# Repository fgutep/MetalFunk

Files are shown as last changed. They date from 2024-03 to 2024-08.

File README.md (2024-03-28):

# The metalFu(n)k 3D printer
Why call it that:
Used to be:
- A3D-One (When I was 16).
- MetalHunk (Because the full-metal frame is the best thing about it)
**Its now:**
- Metal Fuk. Because its a PITA. But being funky sounds kinder to it. 
------------

This 3D printer I started designing at the age of 16. Present day me is still suffering from the consequences of attempting to make such a thing without all the knowledge required. 
While it's been a very, very *edcuative* process, I'm now tryiong to make something useful out of it as it:
- Costed money to make (~400 USD then plus at least an aditional $100 while trying to make it work).
- Is a Pain in the 4$$.
- It would be nice to have a working 3D printer that I can proudly say "No one else in the world has this".
## Specs and Features:
- The sturdiest and most expensive frame you'll see in a while made fully of 2040 and 2020 T-Slot aluminum extrusion profiles.
- A BMG Bowden extruder.
- A custom (but full compromise) SLIM (and I mean **slim**) extruder I made for the Ender/CR Hotend.
- The novelty, antique and legendary **Ramps 1.4** which means it **runs on an Arduino Mega** <code style = "color : greenyellow">Will fix to support the Ender 3 -  4.2.7 Non-Silent Board OR the BIGTREETECH SKR Mini E3 V3.0).</code>.
- Marlin 2.0.1.
Double Z-Axis (Which is apparently a feature nowadays).
- <code style = "color : orangered"> Not a single V-Roller in sight besides being fully made in 2020 and 2040 T-Slot. Which is a problem. Will fix someday.</code>.

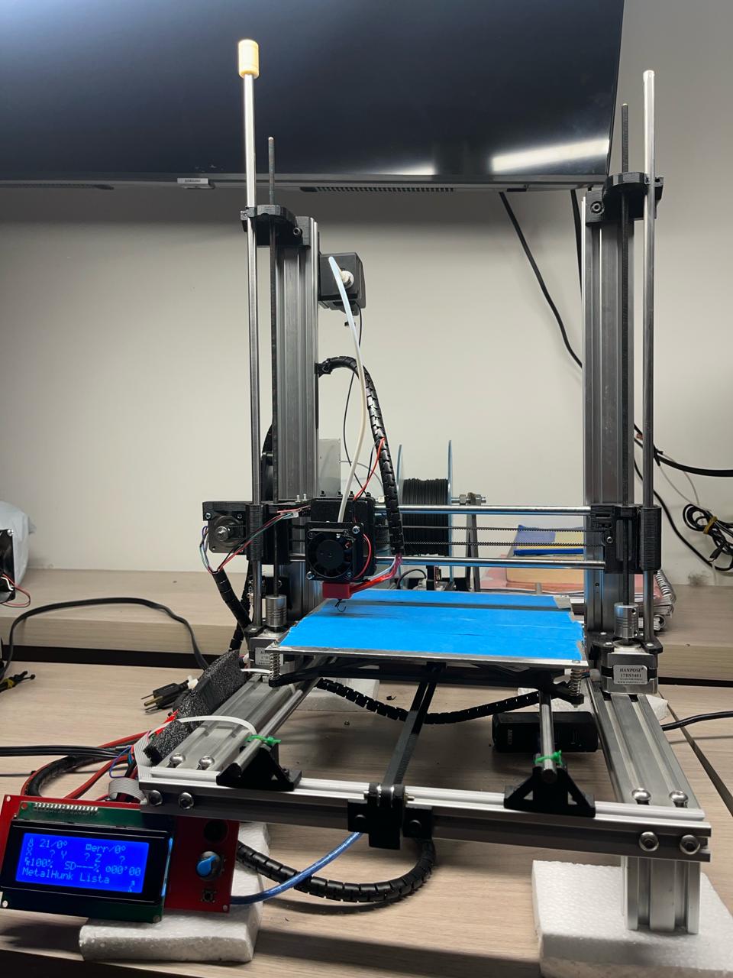
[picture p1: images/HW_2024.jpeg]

>> As of March 2024 it looks like this.

## Where am I with the development:
**Facts:**
- It has a decent and usable aluminum frame.
- It moves (It didnt use to).
- It does **not** caugh fire (it used to).
- It prints (Like *S*ugar *H*oney *I*ced *T*ea Tho).

### What I do not understand:
- The thing skips layers when printing anything above 40 minutes and starts shifting the object upfront making it unusable.
- Current of the motors. Only god and the guy who made them knows what current do they really use. While the *17HS3401* pancake Nema 17 motors i'm using have 1.2 Amps in their data sheet; they overheat a LOT when using that. Seem to run fine at 1/2 of the datasheet current and make a lot of noise anything below that.

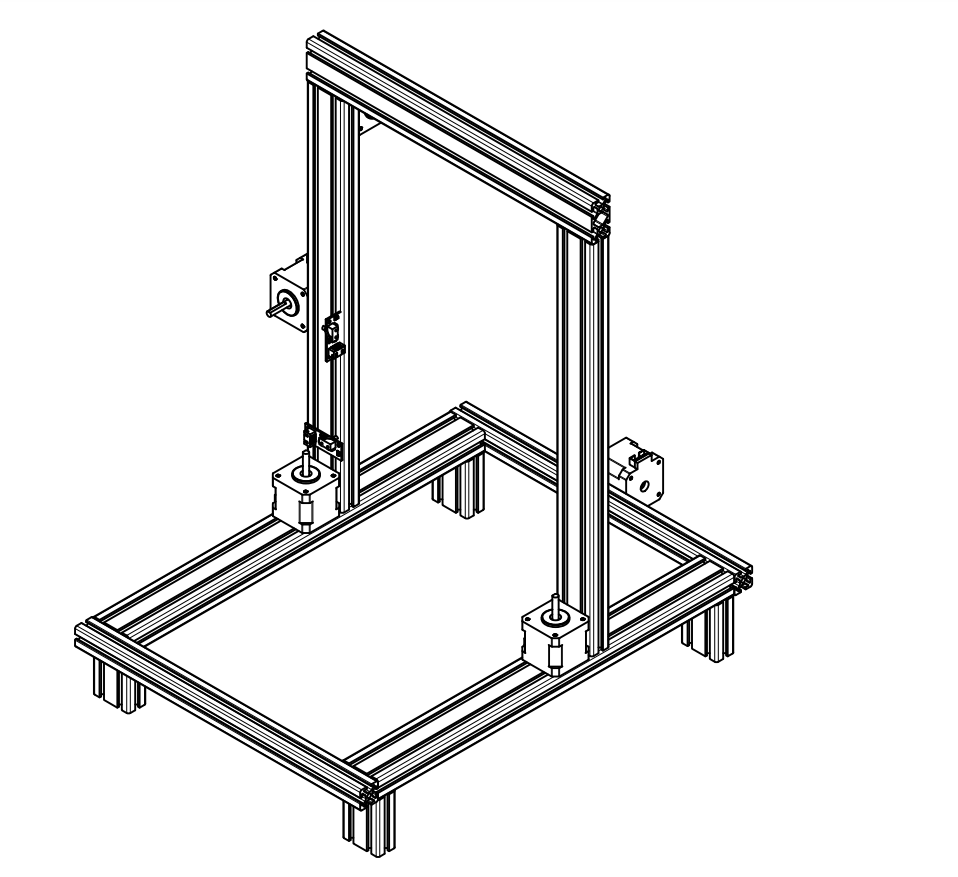
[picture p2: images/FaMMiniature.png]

>> The Uploaded CAD File. Note that only includes metal frame and motors/endStops as every plastic piece needs to be re-designed from scratch.

## Goals and To-Do:
- **1. Re-Design and re-print every.single.piece.of.plastic**. By this I mean every piece of 3D printed material as it's a frankenstein adaptation that I made between the [Prusa Rework](https://reprap.org/wiki/Prusa_i3_Rework_Introduction "Prusa Rework") that I was comftable since it was my first 3D printer and what I managed to make of those parts *i.e. in TinkerCAD* as an adaptation to the V-Slot profile frame.
- **2. Put a better board in it** like the aforementioned 4.2.7 Non-Silent Board OR the BIGTREETECH SKR Mini E3 V3.0. As I suspect 90% of my problems have to do with using *The Defunkt RAMPS*.
- **3. Make it print Reliably** Which I suspect with a new board in place, and with the new parts should be easier.
- **4. Extruder** Make it look pro, and add a colling fan, light and better cable management.
- **5. Asthetics** It looks like a *MetalHunk* it should look nice, or at the very least funny. It should have a personality to it.
- **6. Add V-Roller Based Kinematics** it is Unaceptable for it to use smooth rods and linear bearing in the date and time we are in.
- **7. The SkyisTheLimit** Input shapping, really high speeds, really quiet, wireless conectivity, the ability to print upsuide down or sideways. Whatever. But first we need to meet every previous objective.

When will the objectives be met?
When they are. I Hope that By Summer 2024 I am at least by objective **#4**. But I am not putting a hard deadline on it either as I am an EE and CS student and work with *a lot* of teams, sideprojects and sidequests on a daily basis appart from this one.  

*Note-to-self:* If By August 2024 objective #3 is not met, the project might be scrapped as the value to keep going might be usustainable. 

##### Last update of the readme:
27/03/2024

### Man Hours:
| When | Who | How Many |
| --- | --- | --- |
|  2019-2020 | Fgutep  | 50+ Hours  |
| Dec 2023- Jan 2024  | Fgutep  |  20+ Hours |
| March 2024 (Holy Week) | Fgutep  |  10+ Hours |
| |  Total ATM | ~80 Hours atleast  |

A free tip: Dont design, make and document a 3D printer as a 9th grade school project.

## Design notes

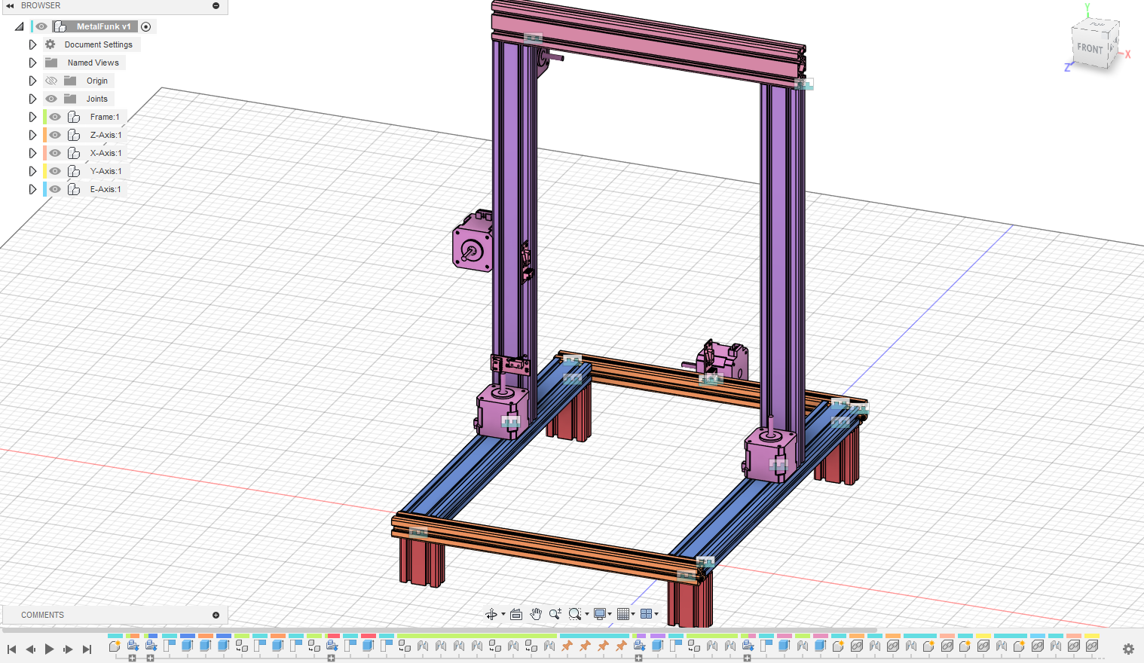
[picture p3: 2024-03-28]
images/F360_HW.png

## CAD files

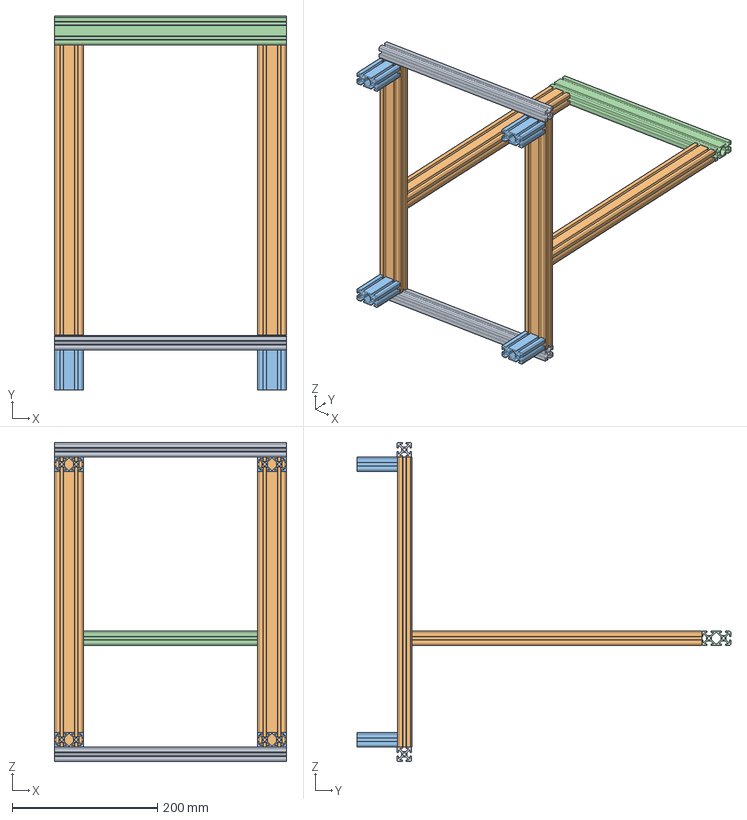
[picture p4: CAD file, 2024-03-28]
3DModels/Assembly/OnlyFrame.step
320.0 x 515.3 x 440.0 mm
2020- XA x 2
2040 - YA x 2
2040 - Z_Leg x 4
2040 - ZMain x 2
Frame Top

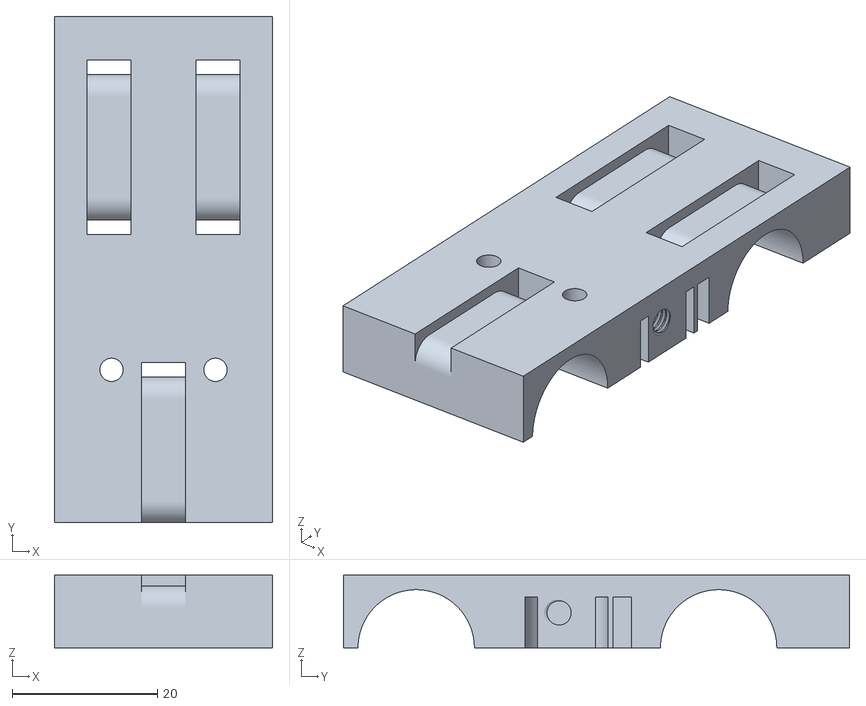
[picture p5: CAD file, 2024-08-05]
3DModels/X-Axis/Extruder/Extruder Back.stl
30.0 x 69.6 x 10.0

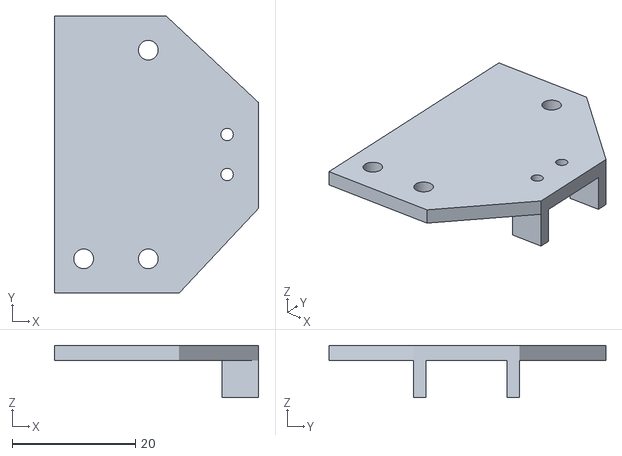
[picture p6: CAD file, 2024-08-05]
3DModels/X-Axis/X-Endstop-Adapter.stl
33.1 x 45.0 x 8.50

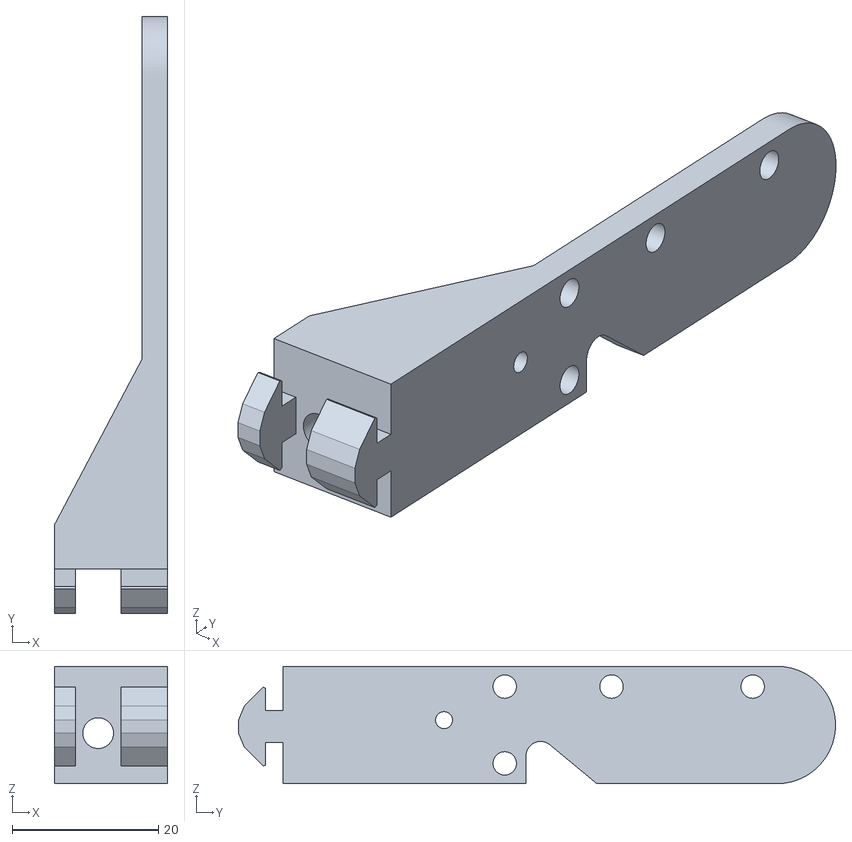
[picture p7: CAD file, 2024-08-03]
3DModels/Y-Axis/Y-EndStop.stl
15.5 x 81.6 x 16.0

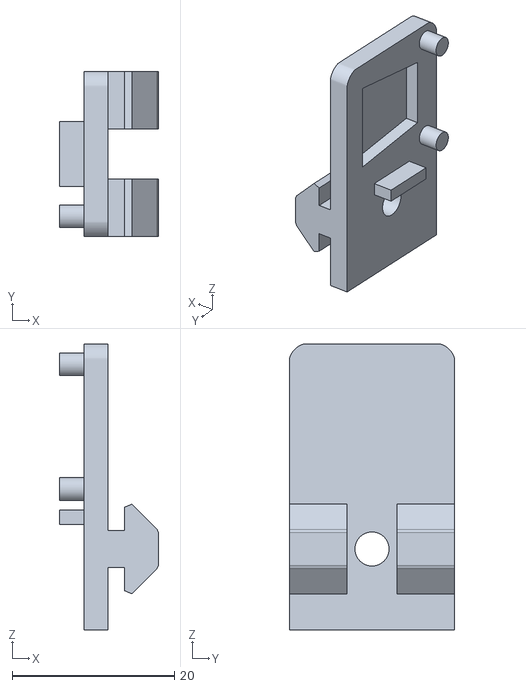
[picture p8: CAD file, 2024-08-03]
3DModels/Z-Axis/Z-Endstop-V1.stl
12.2 x 20.4 x 35.3

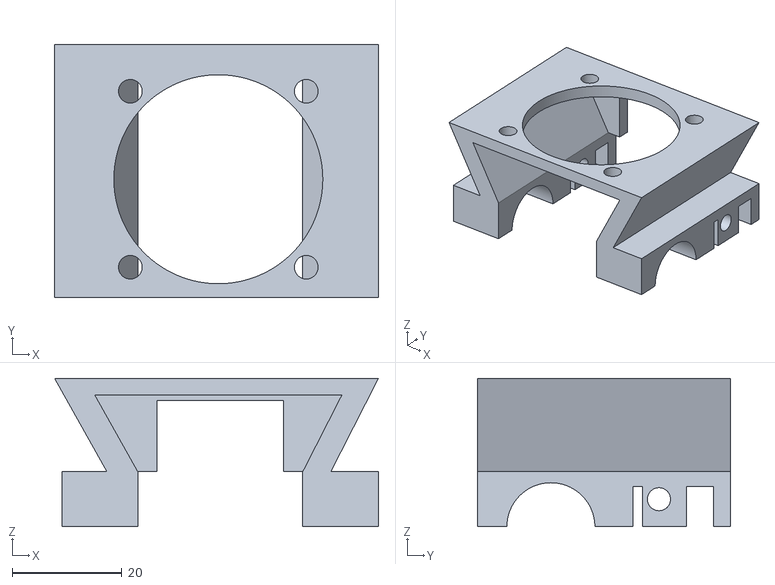
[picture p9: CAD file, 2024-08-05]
3DModels/X-Axis/Extruder/Extruder Shroud.stl
58.9 x 46.0 x 27.0

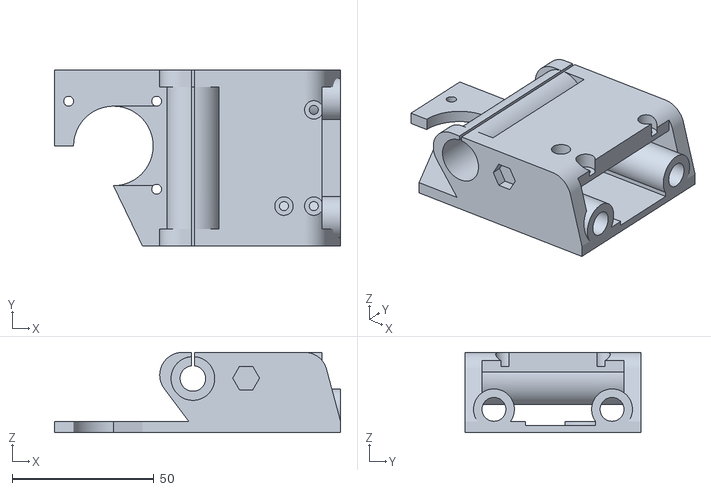
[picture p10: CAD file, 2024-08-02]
3DModels/X-Axis/X-Motor.stl
100.8 x 62.0 x 28.3

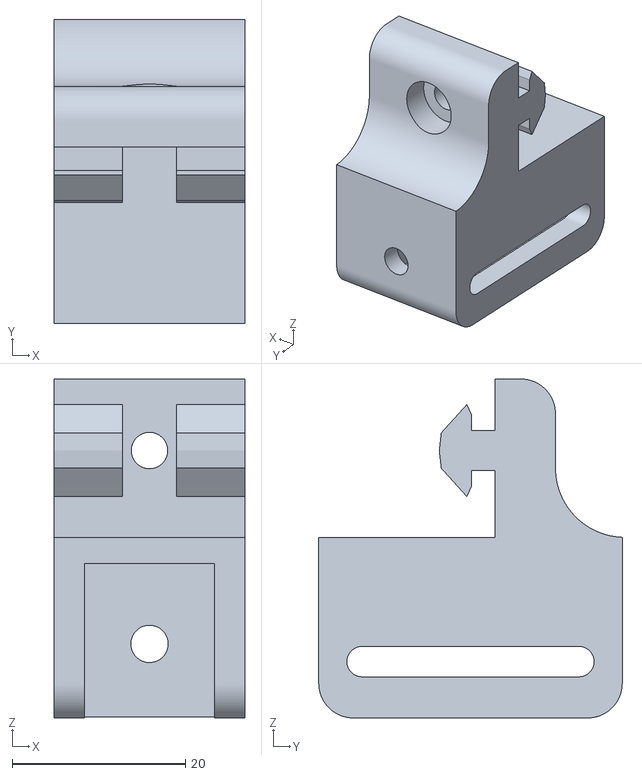
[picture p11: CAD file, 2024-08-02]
3DModels/Y-Axis/Y-Pulley-Tensioner.stl
22.0 x 35.0 x 39.1

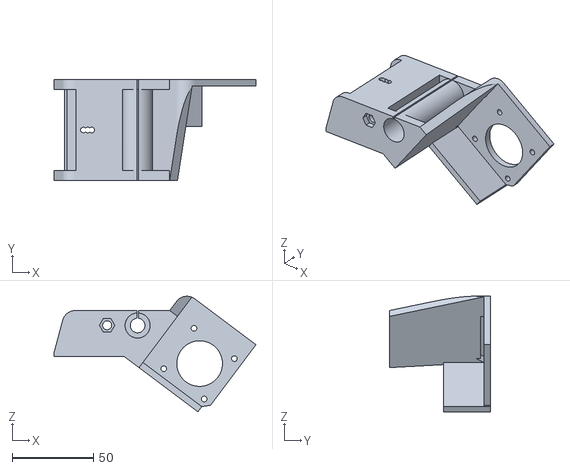
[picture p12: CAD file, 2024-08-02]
3DModels/X-Axis/X-Idler-and-BMG.stl
124.0 x 62.0 x 71.0

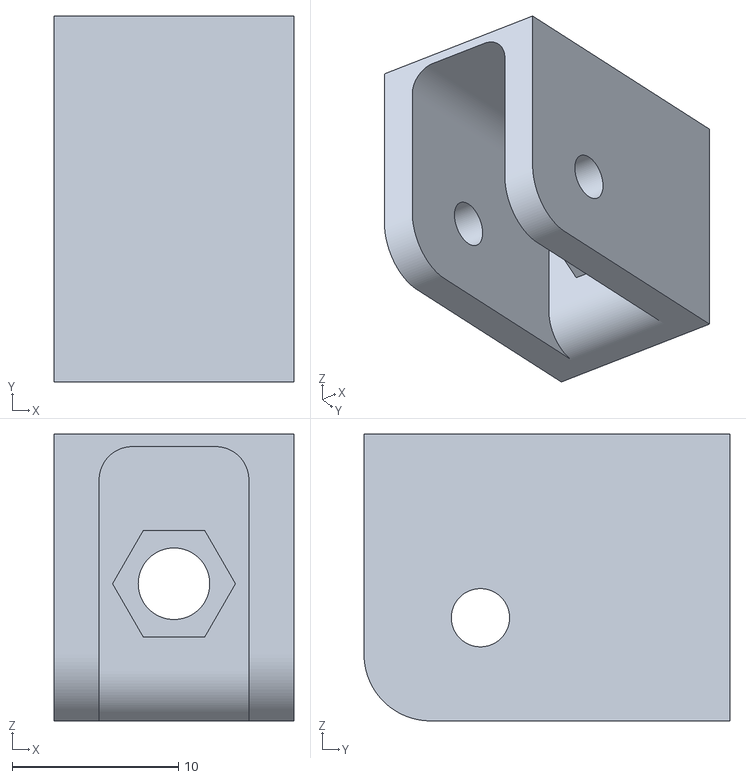
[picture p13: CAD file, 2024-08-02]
3DModels/Y-Axis/Y-Pulley Idler-Craddle.stl
14.4 x 22.0 x 17.2

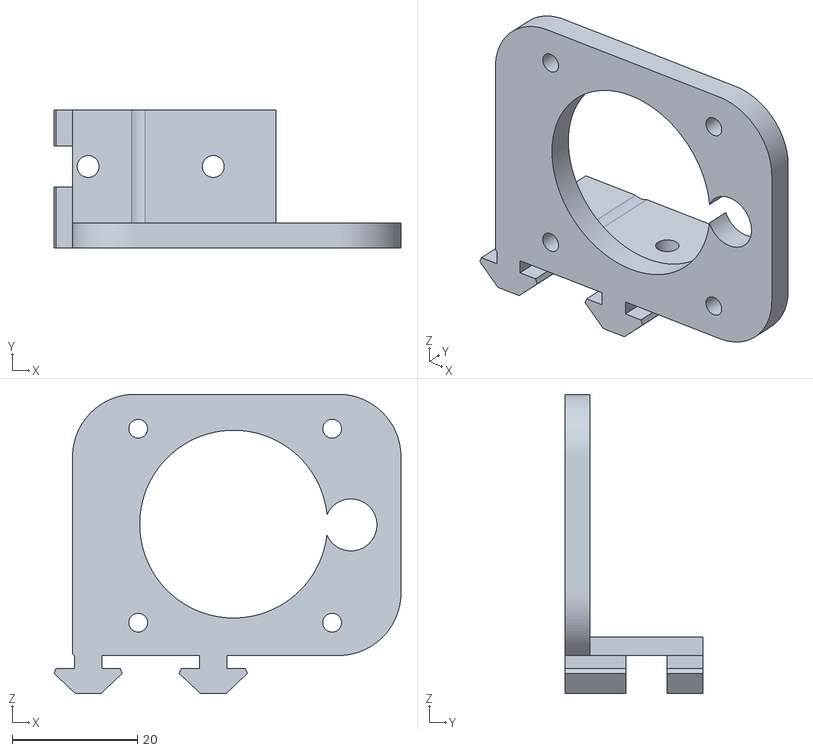
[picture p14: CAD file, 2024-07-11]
3DModels/Z-Axis/Z-Axis Right Motor Brace.stl
55.5 x 22.0 x 47.8

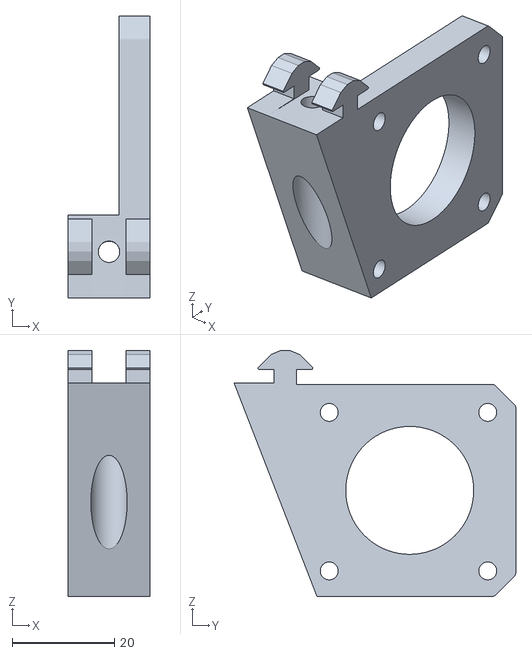
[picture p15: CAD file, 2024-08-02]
3DModels/Y-Axis/Y-MotorBracket.stl
16.0 x 55.1 x 48.1

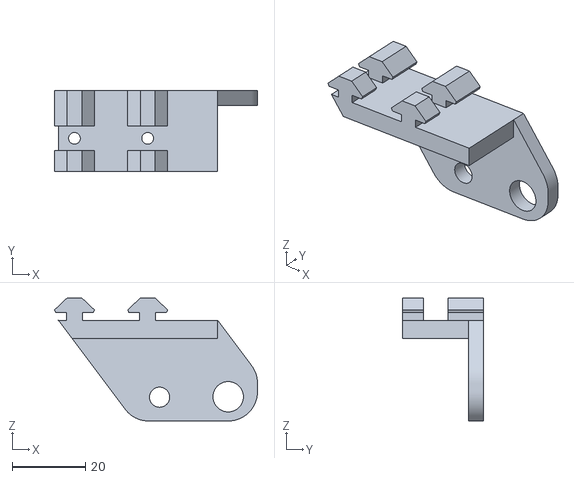
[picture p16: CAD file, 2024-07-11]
3DModels/Z-Axis/Z-Axis Left Top Brace.stl
55.5 x 22.0 x 33.6

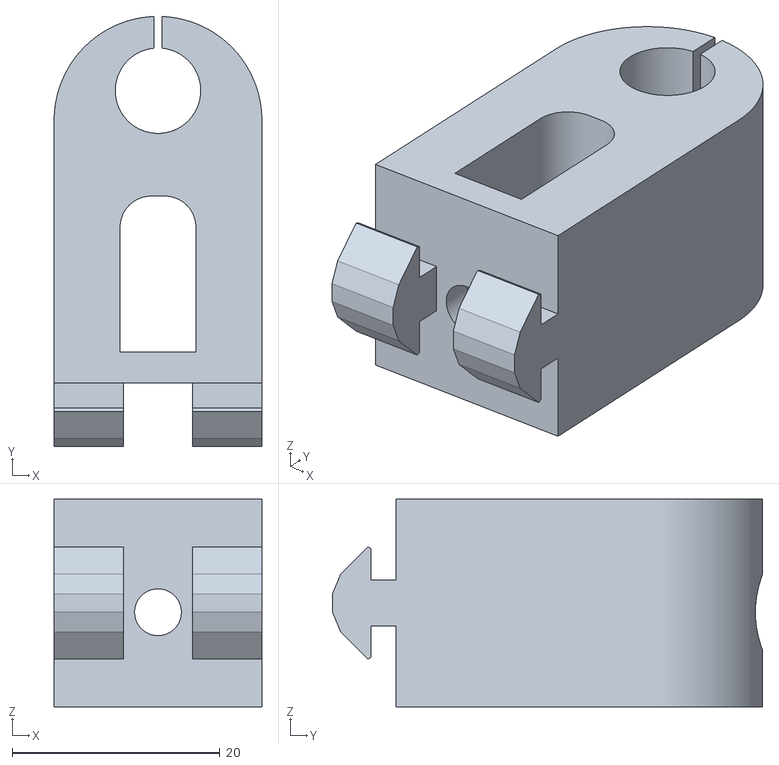
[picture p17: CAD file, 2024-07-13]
3DModels/Y-Axis/Y-Rod-Bracket_Back.stl
20.0 x 41.4 x 20.0

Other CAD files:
3DModels/Z-Axis/Z-Axis Left Motor Brace.stl
3DModels/Y-Axis/Y-Rod-Bracket_Front.stl
3DModels/Z-Axis/Z-Axis Right Top Brace.stl
3DModels/Y-Axis/Y-Belt-Idler.stl
3DModels/Assembly/MetalFunk Assembly.f3z
3DModels/Assembly/OnlyFrame.f3d
3DModels/Z-Axis/M3_Washer.stl

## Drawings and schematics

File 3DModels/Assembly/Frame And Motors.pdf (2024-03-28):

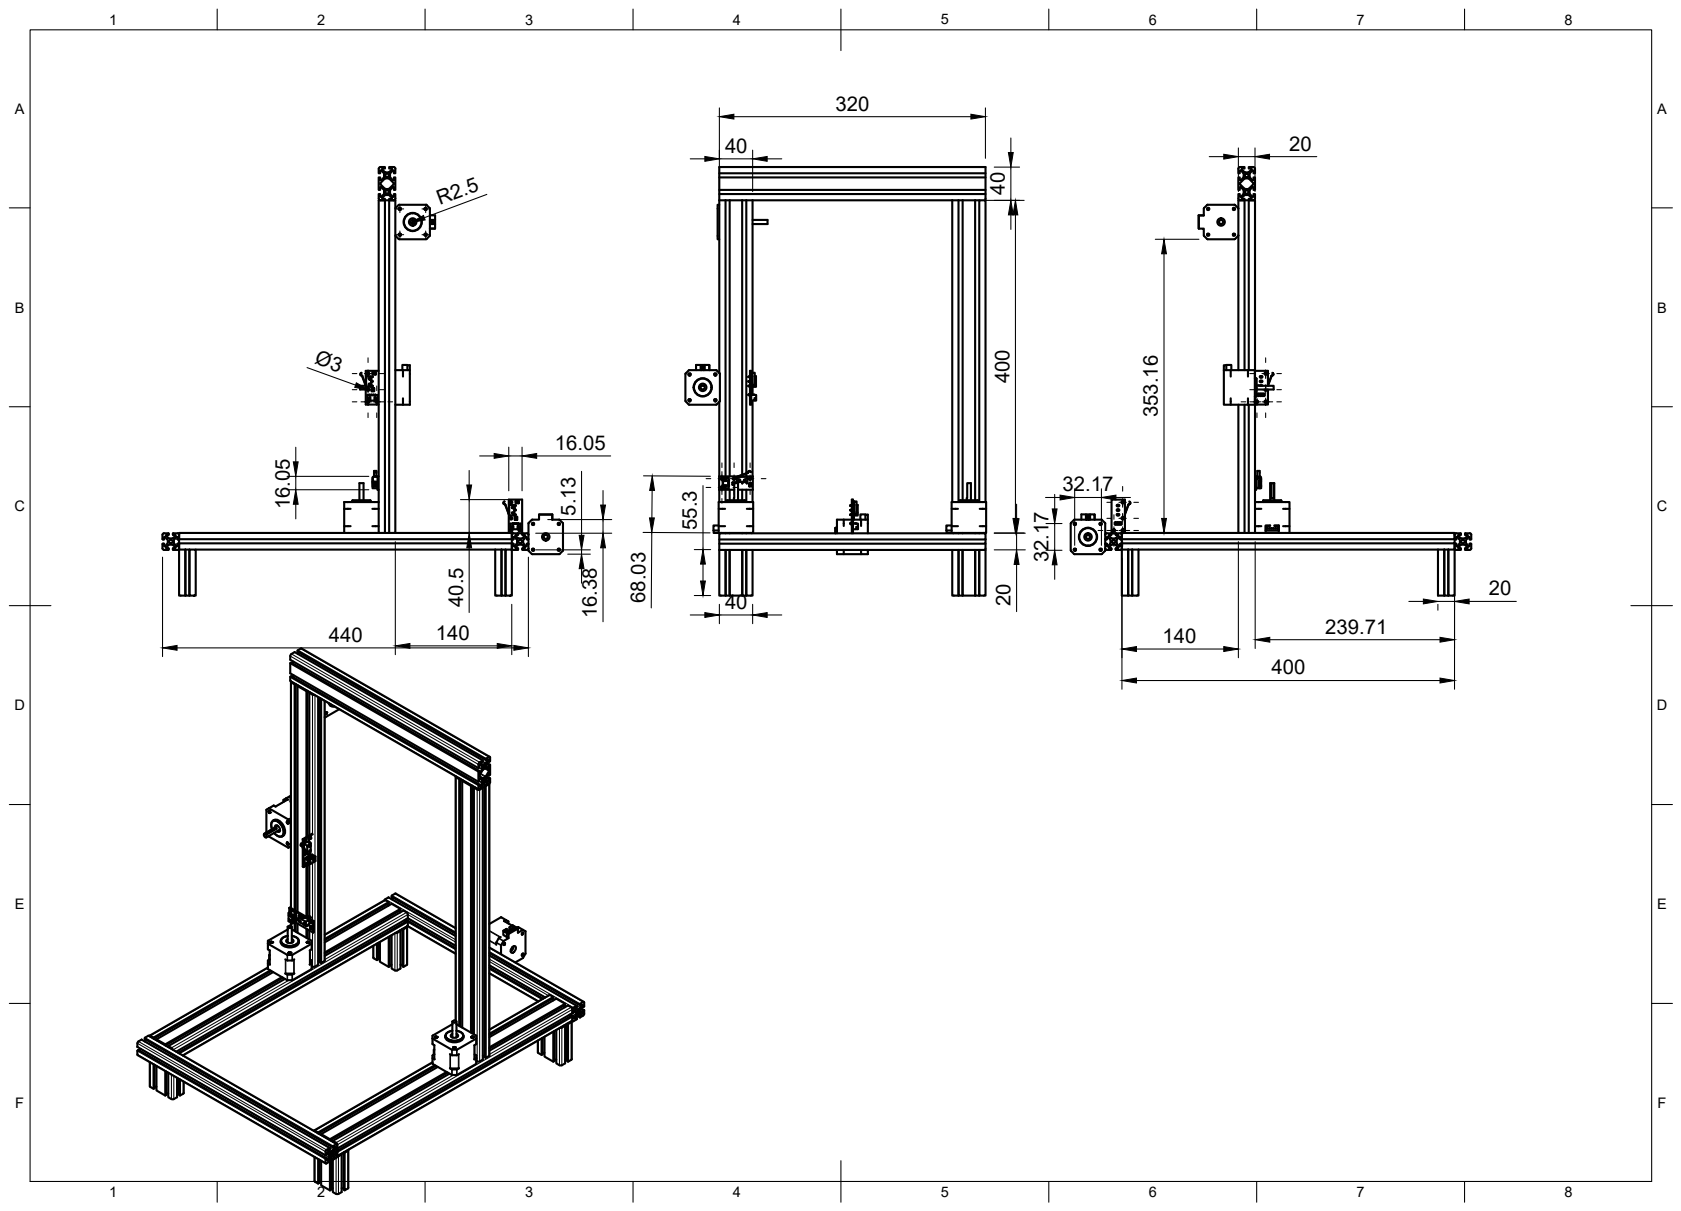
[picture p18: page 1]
8 BCDEF; ABCDEF 55.3 68.03

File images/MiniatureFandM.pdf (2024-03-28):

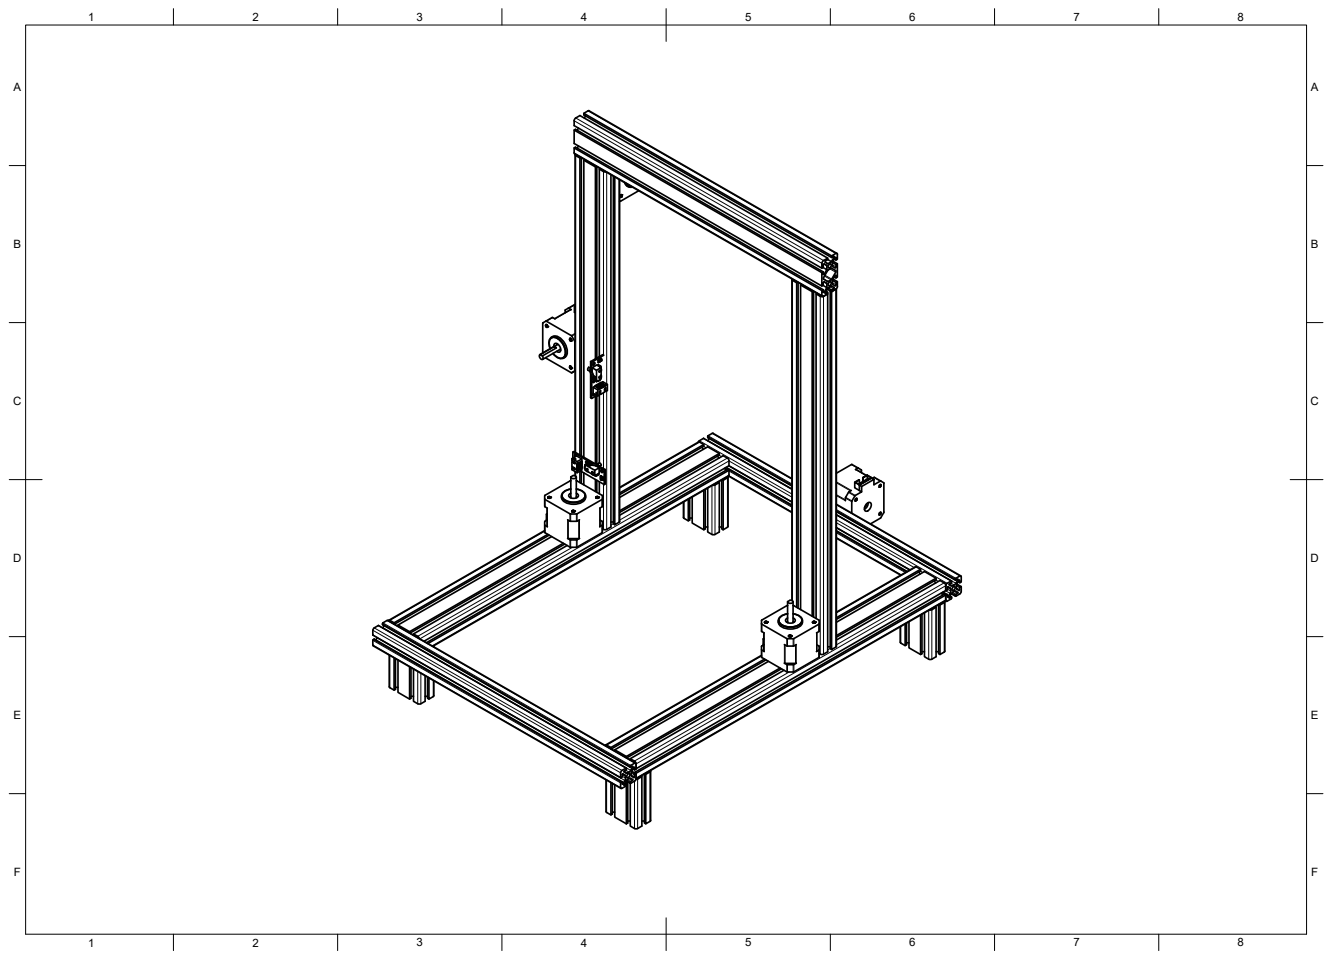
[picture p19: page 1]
8 BCDEF; ABCDEF

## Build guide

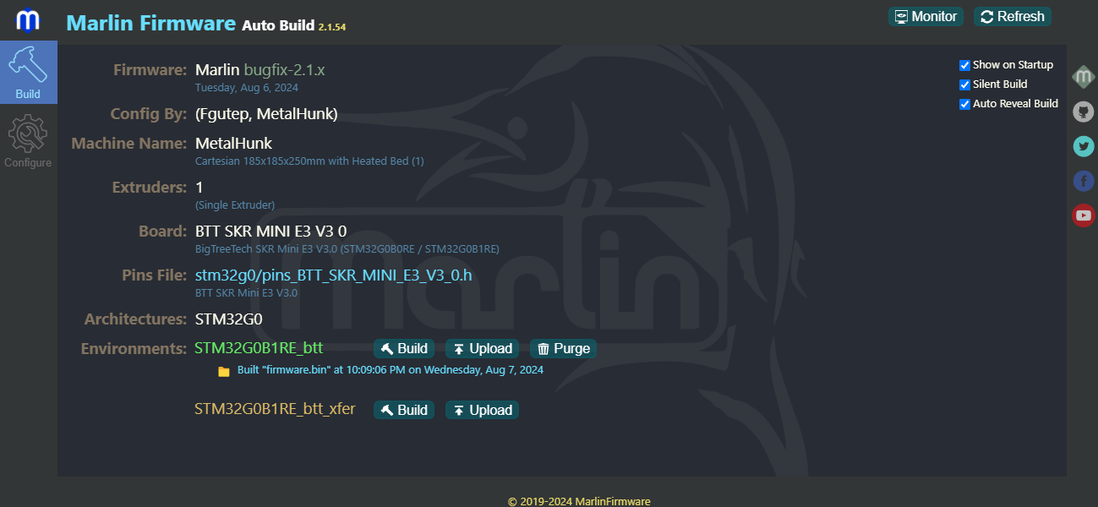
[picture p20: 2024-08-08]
images/MARLIN_Latest_Build.png

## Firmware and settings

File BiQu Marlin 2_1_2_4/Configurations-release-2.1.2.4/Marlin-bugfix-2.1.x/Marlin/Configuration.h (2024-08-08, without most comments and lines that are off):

#pragma once
#define CONFIG_EXAMPLES_DIR "Creality/Ender-3 Pro/BigTreeTech SKR Mini E3 3.0"
#define CONFIGURATION_H_VERSION 02010300
#define STRING_CONFIG_H_AUTHOR "(Fgutep, MetalHunk)" // Who made the changes.
  #define MOTHERBOARD BOARD_BTT_SKR_MINI_E3_V3_0
#define SERIAL_PORT 2
#define BAUDRATE 115200
#define SERIAL_PORT_2 -1
#define CUSTOM_MACHINE_NAME "MetalHunk"
#define X_DRIVER_TYPE  TMC2209
#define Y_DRIVER_TYPE  TMC2209
#define Z_DRIVER_TYPE  TMC2209
#define E0_DRIVER_TYPE TMC2209
#define EXTRUDERS 1
#define DEFAULT_NOMINAL_FILAMENT_DIA 1.75
#define TEMP_SENSOR_0 1
#define TEMP_SENSOR_1 0
#define TEMP_SENSOR_2 0
#define TEMP_SENSOR_3 0
#define TEMP_SENSOR_4 0
#define TEMP_SENSOR_5 0
#define TEMP_SENSOR_6 0
#define TEMP_SENSOR_7 0
#define TEMP_SENSOR_BED 1
#define TEMP_SENSOR_PROBE 0
#define TEMP_SENSOR_CHAMBER 0
#define TEMP_SENSOR_COOLER 0
#define TEMP_SENSOR_BOARD 0
#define TEMP_SENSOR_SOC 0
#define TEMP_SENSOR_REDUNDANT 0
#define DUMMY_THERMISTOR_998_VALUE  25
#define DUMMY_THERMISTOR_999_VALUE 100
#if TEMP_SENSOR_IS_MAX_TC(0)
  #define MAX31865_SENSOR_OHMS_0      100 // (Ω) Typically 100 or 1000 (PT100 or PT1000)
  #define MAX31865_CALIBRATION_OHMS_0 430 // (Ω) Typically 430 for Adafruit PT100; 4300 for Adafruit PT1000
#endif
#if TEMP_SENSOR_IS_MAX_TC(1)
  #define MAX31865_SENSOR_OHMS_1      100
  #define MAX31865_CALIBRATION_OHMS_1 430
#endif
#if TEMP_SENSOR_IS_MAX_TC(2)
  #define MAX31865_SENSOR_OHMS_2      100
  #define MAX31865_CALIBRATION_OHMS_2 430
#endif
#if HAS_E_TEMP_SENSOR
  #define TEMP_RESIDENCY_TIME         10  // (seconds) Time to wait for hotend to "settle" in M109
  #define TEMP_WINDOW                  1  // (°C) Temperature proximity for the "temperature reached" timer
  #define TEMP_HYSTERESIS              3  // (°C) Temperature proximity considered "close enough" to the target
#endif
#if TEMP_SENSOR_BED
  #define TEMP_BED_RESIDENCY_TIME     10  // (seconds) Time to wait for bed to "settle" in M190
  #define TEMP_BED_WINDOW              1  // (°C) Temperature proximity for the "temperature reached" timer
  #define TEMP_BED_HYSTERESIS          3  // (°C) Temperature proximity considered "close enough" to the target
#endif
#if TEMP_SENSOR_CHAMBER
  #define TEMP_CHAMBER_RESIDENCY_TIME 10  // (seconds) Time to wait for chamber to "settle" in M191
  #define TEMP_CHAMBER_WINDOW          1  // (°C) Temperature proximity for the "temperature reached" timer
  #define TEMP_CHAMBER_HYSTERESIS      3  // (°C) Temperature proximity considered "close enough" to the target
#endif
#if TEMP_SENSOR_REDUNDANT
  #define TEMP_SENSOR_REDUNDANT_SOURCE    E1  // The sensor that will provide the redundant reading.
  #define TEMP_SENSOR_REDUNDANT_TARGET    E0  // The sensor that we are providing a redundant reading for.
  #define TEMP_SENSOR_REDUNDANT_MAX_DIFF  10  // (°C) Temperature difference that will trigger a print abort.
#endif
#define HEATER_0_MINTEMP   5
#define HEATER_1_MINTEMP   5
#define HEATER_2_MINTEMP   5
#define HEATER_3_MINTEMP   5
#define HEATER_4_MINTEMP   5
#define HEATER_5_MINTEMP   5
#define HEATER_6_MINTEMP   5
#define HEATER_7_MINTEMP   5
#define BED_MINTEMP        5
#define CHAMBER_MINTEMP    5
#define HEATER_0_MAXTEMP 275
#define HEATER_1_MAXTEMP 275
#define HEATER_2_MAXTEMP 275
#define HEATER_3_MAXTEMP 275
#define HEATER_4_MAXTEMP 275
#define HEATER_5_MAXTEMP 275
#define HEATER_6_MAXTEMP 275
#define HEATER_7_MAXTEMP 275
#define BED_MAXTEMP      125
#define CHAMBER_MAXTEMP  60
#define HOTEND_OVERSHOOT 15   // (°C) Forbid temperatures over MAXTEMP - OVERSHOOT
#define BED_OVERSHOOT    10   // (°C) Forbid temperatures over MAXTEMP - OVERSHOOT
#define COOLER_OVERSHOOT  2   // (°C) Forbid temperatures closer than OVERSHOOT
#define PIDTEMP           // See the PID Tuning Guide at https://reprap.org/wiki/PID_Tuning
#define PID_MAX  255      // Limit hotend current while PID is active (see PID_FUNCTIONAL_RANGE below); 255=full current
#define PID_K1     0.95   // Smoothing factor within any PID loop
    #define DEFAULT_Kp  21.73
    #define DEFAULT_Ki   1.54
    #define DEFAULT_Kd  76.55
#define MAX_BED_POWER 255 // limits duty cycle to bed; 255=full current
#define PIDTEMPBED
  #define DEFAULT_bedKp 50.71
  #define DEFAULT_bedKi 9.88
  #define DEFAULT_bedKd 173.43
#define MAX_CHAMBER_POWER 255 // limits duty cycle to chamber heater; 255=full current
  #define PID_FUNCTIONAL_RANGE 10 // If the temperature difference between the target temperature and the actual temperature
#define PREVENT_COLD_EXTRUSION
#define EXTRUDE_MINTEMP 170
#define PREVENT_LENGTHY_EXTRUDE
#define EXTRUDE_MAXLENGTH 600
#define THERMAL_PROTECTION_HOTENDS // Enable thermal protection for all extruders
#define THERMAL_PROTECTION_BED     // Enable thermal protection for the heated bed
#define THERMAL_PROTECTION_CHAMBER // Enable thermal protection for the heated chamber
#define THERMAL_PROTECTION_COOLER  // Enable thermal protection for the laser cooling
#define ENDSTOPPULLUPS
#define X_MIN_ENDSTOP_HIT_STATE LOW //! Endstop invert cambiar si necesario
#define X_MAX_ENDSTOP_HIT_STATE HIGH
#define Y_MIN_ENDSTOP_HIT_STATE LOW //! Endstop invert cambiar si necesario
#define Y_MAX_ENDSTOP_HIT_STATE HIGH
#define Z_MIN_ENDSTOP_HIT_STATE HIGH //! Endstop invert cambiar si necesario
#define Z_MAX_ENDSTOP_HIT_STATE HIGH
#define I_MIN_ENDSTOP_HIT_STATE HIGH
#define I_MAX_ENDSTOP_HIT_STATE HIGH
#define J_MIN_ENDSTOP_HIT_STATE HIGH
#define J_MAX_ENDSTOP_HIT_STATE HIGH
#define K_MIN_ENDSTOP_HIT_STATE HIGH
#define K_MAX_ENDSTOP_HIT_STATE HIGH
#define U_MIN_ENDSTOP_HIT_STATE HIGH
#define U_MAX_ENDSTOP_HIT_STATE HIGH
#define V_MIN_ENDSTOP_HIT_STATE HIGH
#define V_MAX_ENDSTOP_HIT_STATE HIGH
#define W_MIN_ENDSTOP_HIT_STATE HIGH
#define W_MAX_ENDSTOP_HIT_STATE HIGH
#define Z_MIN_PROBE_ENDSTOP_HIT_STATE HIGH
#define ENDSTOP_INTERRUPTS_FEATURE
#define DEFAULT_AXIS_STEPS_PER_UNIT   { 80, 80, 400, 93 }
#define EDITABLE_STEPS_PER_UNIT
#define DEFAULT_MAX_FEEDRATE          { 500, 500, 5, 25 }
#define DEFAULT_MAX_ACCELERATION      { 500, 500, 150, 5000 }
#define DEFAULT_ACCELERATION                   500  // X, Y, Z ... and E acceleration for printing moves
#define DEFAULT_RETRACT_ACCELERATION           500  // E acceleration for retracts
#define DEFAULT_TRAVEL_ACCELERATION            500  // X, Y, Z ... acceleration for travel (non printing) moves
  #define JUNCTION_DEVIATION_MM 0.08  // (mm) Distance from real junction edge
  #define JD_HANDLE_SMALL_SEGMENTS    // Use curvature estimation instead of just the junction angle
#define S_CURVE_ACCELERATION
#define Z_MIN_PROBE_USES_Z_MIN_ENDSTOP_PIN
#define NOZZLE_TO_PROBE_OFFSET { 10, 10, 0 }
#define PROBING_TOOL 0
#define PROBING_MARGIN 10
#define XY_PROBE_FEEDRATE (133*60)
#define Z_PROBE_FEEDRATE_FAST (4*60)
#define Z_PROBE_FEEDRATE_SLOW (Z_PROBE_FEEDRATE_FAST / 2)
#define Z_CLEARANCE_DEPLOY_PROBE   10 // (mm) Z Clearance for Deploy/Stow
#define Z_CLEARANCE_BETWEEN_PROBES  5 // (mm) Z Clearance between probe points
#define Z_CLEARANCE_MULTI_PROBE     5 // (mm) Z Clearance between multiple probes
#define Z_PROBE_ERROR_TOLERANCE     3 // (mm) Tolerance for early trigger (<= -probe.offset.z + ZPET)
#define Z_PROBE_LOW_POINT          -2 // (mm) Farthest distance below the trigger-point to go before stopping
#define X_ENABLE_ON 0
#define Y_ENABLE_ON 0
#define Z_ENABLE_ON 0
#define E_ENABLE_ON 0 // For all extruders
#define DISABLE_OTHER_EXTRUDERS   // Keep only the active extruder enabled
#define INVERT_X_DIR true
#define INVERT_Y_DIR true
#define INVERT_Z_DIR false
#define INVERT_E0_DIR true
#define INVERT_E1_DIR false
#define INVERT_E2_DIR false
#define INVERT_E3_DIR false
#define INVERT_E4_DIR false
#define INVERT_E5_DIR false
#define INVERT_E6_DIR false
#define INVERT_E7_DIR false
#define X_HOME_DIR -1
#define Y_HOME_DIR -1
#define Z_HOME_DIR -1
#define X_BED_SIZE 185
#define Y_BED_SIZE 185
#define X_MIN_POS 0
#define Y_MIN_POS 0
#define Z_MIN_POS 0
#define X_MAX_POS X_BED_SIZE
#define Y_MAX_POS Y_BED_SIZE
#define Z_MAX_POS 250
#define MIN_SOFTWARE_ENDSTOPS
  #define MIN_SOFTWARE_ENDSTOP_X
  #define MIN_SOFTWARE_ENDSTOP_Y
  #define MIN_SOFTWARE_ENDSTOP_Z
  #define MIN_SOFTWARE_ENDSTOP_I
  #define MIN_SOFTWARE_ENDSTOP_J
  #define MIN_SOFTWARE_ENDSTOP_K
  #define MIN_SOFTWARE_ENDSTOP_U
  #define MIN_SOFTWARE_ENDSTOP_V
  #define MIN_SOFTWARE_ENDSTOP_W
#define MAX_SOFTWARE_ENDSTOPS
  #define MAX_SOFTWARE_ENDSTOP_X
  #define MAX_SOFTWARE_ENDSTOP_Y
  #define MAX_SOFTWARE_ENDSTOP_Z
  #define MAX_SOFTWARE_ENDSTOP_I
  #define MAX_SOFTWARE_ENDSTOP_J
  #define MAX_SOFTWARE_ENDSTOP_K
  #define MAX_SOFTWARE_ENDSTOP_U
  #define MAX_SOFTWARE_ENDSTOP_V
  #define MAX_SOFTWARE_ENDSTOP_W
#define MESH_BED_LEVELING
  #define MANUAL_PROBE_START_Z 0.2  // (mm) Comment out to use the last-measured height
  #define ENABLE_LEVELING_FADE_HEIGHT
    #define DEFAULT_LEVELING_FADE_HEIGHT 10.0 // (mm) Default fade height.
  #define SEGMENT_LEVELED_MOVES
  #define LEVELED_SEGMENT_LENGTH 5.0 // (mm) Length of all segments (except the last one)
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

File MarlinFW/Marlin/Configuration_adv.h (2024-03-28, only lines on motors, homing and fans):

#define E0_AUTO_FAN_PIN -1
#define E1_AUTO_FAN_PIN -1
#define E2_AUTO_FAN_PIN -1
#define E3_AUTO_FAN_PIN -1
#define E4_AUTO_FAN_PIN -1
#define E5_AUTO_FAN_PIN -1
#define E6_AUTO_FAN_PIN -1
#define E7_AUTO_FAN_PIN -1
#define CHAMBER_AUTO_FAN_PIN -1
#define COOLER_AUTO_FAN_PIN -1
#define COOLER_FAN_PIN -1
#define HOMING_BUMP_MM      { 5, 5, 2 }       // (mm) Backoff from endstops after first bump
#define HOMING_BUMP_DIVISOR { 2, 2, 4 }       // Re-Bump Speed Divisor (Divides the Homing Feedrate)
#define MICROSTEP_MODES { 16, 16, 16, 16, 16, 16 } // [1,2,4,8,16]
#define LIN_ADVANCE
  #define LIN_ADVANCE_K 0.22    // Unit: mm compression per 1mm/s extruder speed
#define ADVANCED_PAUSE_FEATURE
  #define ADVANCED_PAUSE_PURGE_FEEDRATE        3  // (mm/s) Extrude feedrate (after loading). Should be slower than load feedrate.
  #define ADVANCED_PAUSE_PURGE_LENGTH         50  // (mm) Length to extrude after loading.
  #define ADVANCED_PAUSE_RESUME_PRIME          0  // (mm) Extra distance to prime nozzle after returning from park.

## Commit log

2024-03-28 2024- March Latest Marlin and Base Frame and Motors 3D Models
    [Configuration.h, Configuration_adv.h, MetalFunk.f3z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]
2024-07-11 Z-Axis pieces braces
    [Z-Axis Left Motor Brace.stl, Z-Axis Left Top Brace.stl, Z-Axis Right Motor Brace.stl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]
2024-07-11 Main Assembly F3Z file Updated
    [MetalFunk Assembly.f3z, MetalFunk.f3z, MetalFunk.step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]
2024-07-13 Y-Axis Linear Rods Done
    [Y-Belt-Idler.stl, Y-MotorBracket.stl, Y-Rod-Bracket_Back.stl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]
2024-07-16 Avances X Lados
    [Motor Holder.stl]
2024-07-24 Partes Impresas X V1
    [Motor Holder.stl, Motor x Brace Left.stl, Right x Idler BMG.stl]
2024-07-27 x-Axis Right Idler fix
    [Right x Idler BMG.stl]
2024-08-02 Fixed X-Ax messurements, Y Ax PulleyAdv
    [EndStop.stl, Motor x Brace Left.stl, Right x Idler BMG.stl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]
2024-08-02 Fixed idiotic Mistake, renamed few files
    [X-Idler-and-BMG.stl, X-Motor.stl, Y-EndStop.stl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]
2024-08-03 Endstops, Extrusor y par ajustes
    [Extruder Back.stl, Extruder Shroud.stl, M3_Washer.stl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]
2024-08-05 Arreglos Extrusor y endstop x adaptación
    [Extruder Back.stl, Extruder Shroud.stl, X-Endstop-Adapter.stl]
2024-08-08 All of new Marlin for BTT board. Code V1
    [Configuration.h, Configuration_adv.h, esp32.csv]

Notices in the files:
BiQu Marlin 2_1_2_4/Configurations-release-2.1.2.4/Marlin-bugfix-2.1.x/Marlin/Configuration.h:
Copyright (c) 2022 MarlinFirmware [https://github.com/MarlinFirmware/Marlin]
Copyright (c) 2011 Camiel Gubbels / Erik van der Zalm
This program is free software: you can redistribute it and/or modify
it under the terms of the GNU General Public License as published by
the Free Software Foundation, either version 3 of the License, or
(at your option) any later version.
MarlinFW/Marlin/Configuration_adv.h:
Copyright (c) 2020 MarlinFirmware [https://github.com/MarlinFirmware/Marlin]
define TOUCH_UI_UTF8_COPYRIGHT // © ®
